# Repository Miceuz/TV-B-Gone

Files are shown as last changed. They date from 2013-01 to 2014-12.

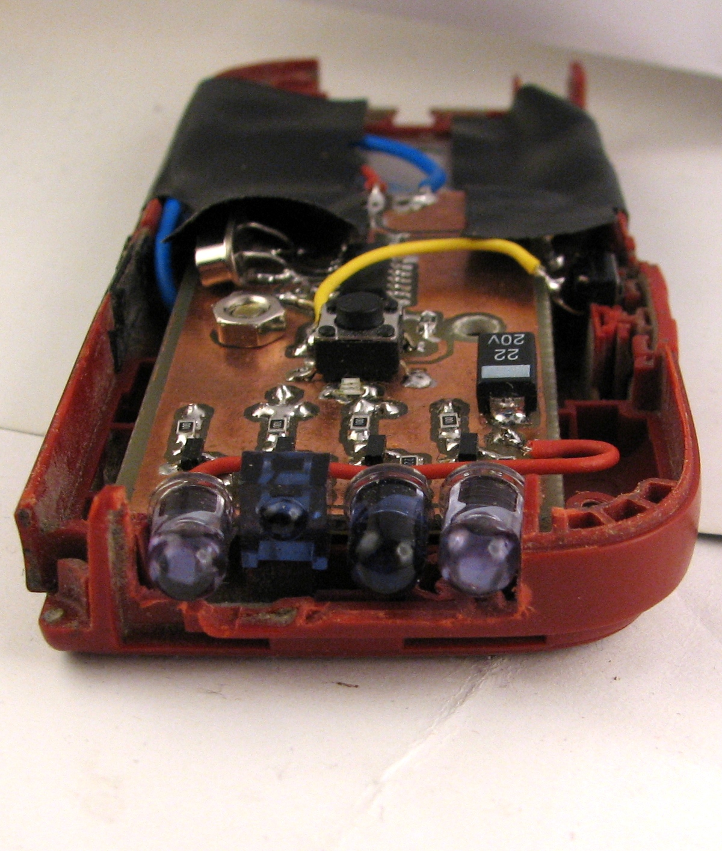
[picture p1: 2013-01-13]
pics/IMG_8425.JPG

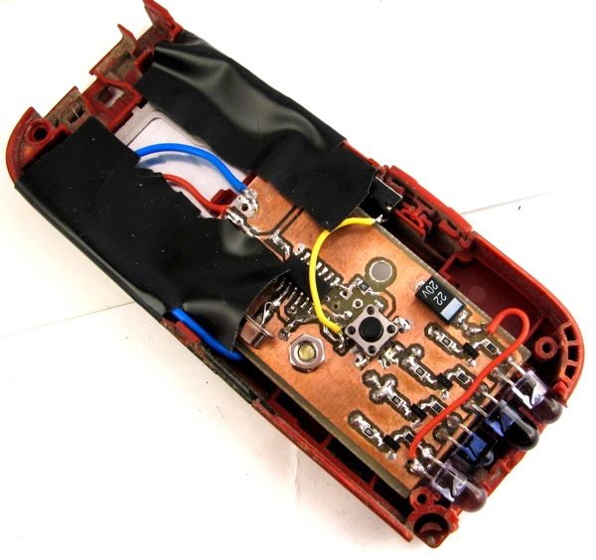
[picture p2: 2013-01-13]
pics/for web/IMG_8424.jpg

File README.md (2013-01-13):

TV-B-Gone
=========

This is my custom TV-be-gone implementation. The board was ment to fit on a standard double AA battery compartment. In general, this design was driven by what parts do I have available in my junk box, thus I've chosen Attiny44  as main microcontroller as I have plenty of them. Leds are driven by mosfets because I had some scavenged from some motherboard.

The code is from Adafruit - https://github.com/adafruit/TV-B-Gone-kit. I've removed all the codes for North American TVs and commented out the biggest codes for European TVs as Attiny44 does not have enough flash to fit them all. I've inverted PWM because I'm driving LEDs via N-channel mosfets, unlike BJTs in Adafruit version.

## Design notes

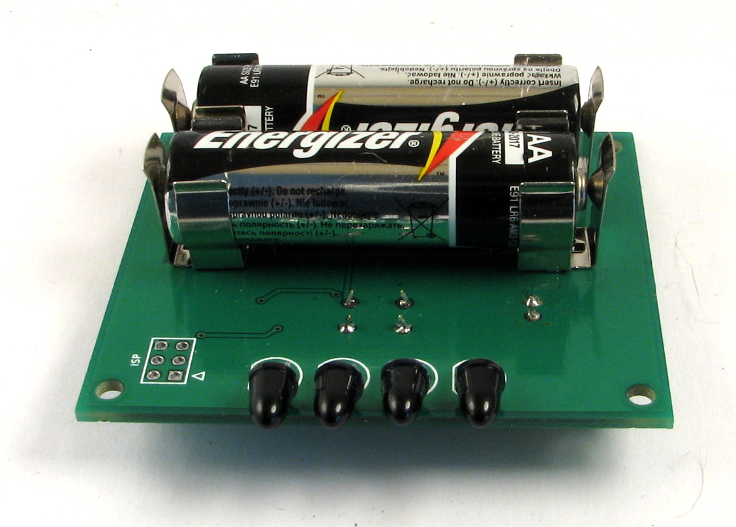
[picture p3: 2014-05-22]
tvbgone-workshop/pics/tv-b-gone-top.jpg

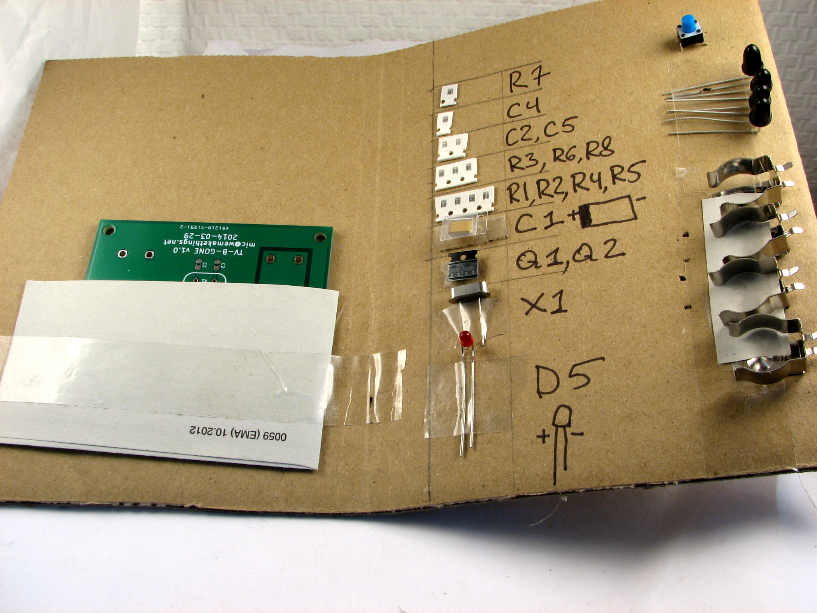
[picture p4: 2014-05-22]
tvbgone-workshop/pics/tv-b-gone-kit.jpg

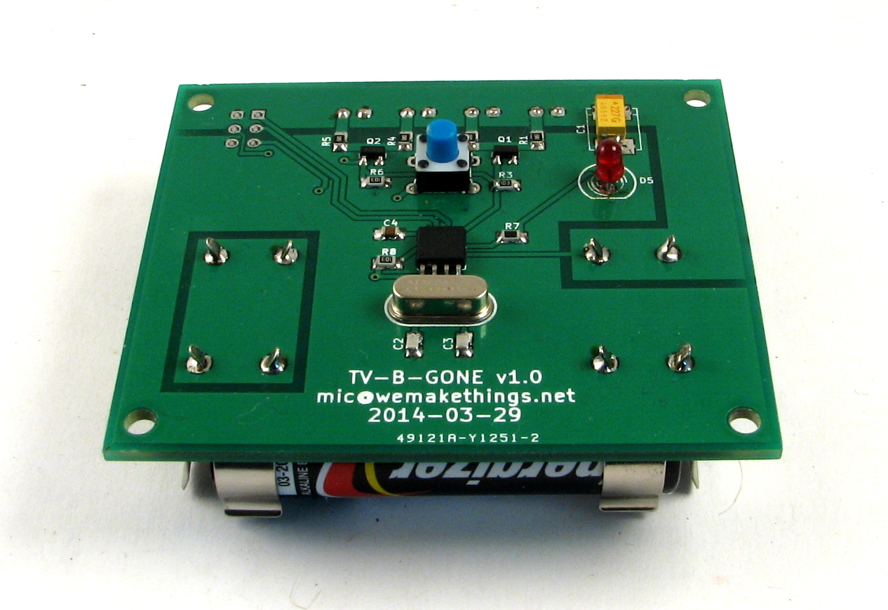
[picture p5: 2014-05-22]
tvbgone-workshop/pics/tv-b-gone-bottom.jpg

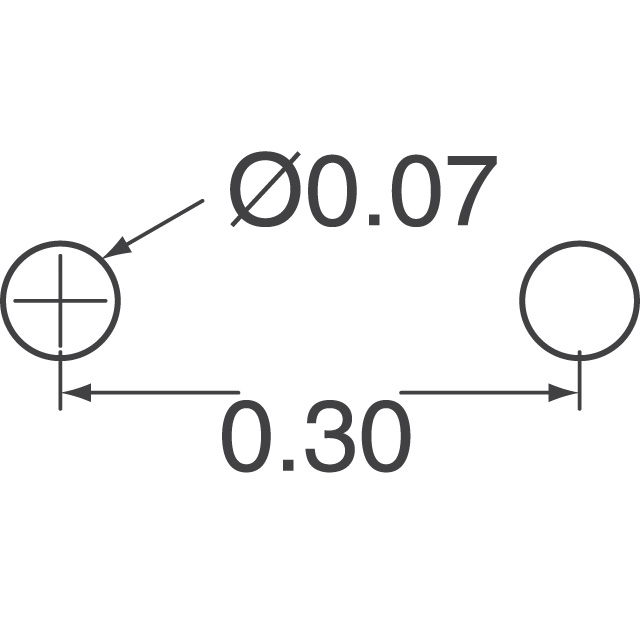
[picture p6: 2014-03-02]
tvbgone-workshop/BK-92FTPRNT.jpg

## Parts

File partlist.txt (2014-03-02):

Partlist

Exported from tvbgone-attiny85-pendant.brd at 2013/04/14/ 10:02 AM

EAGLE Version 5.11.0 Copyright (c) 1988-2010 CadSoft

Part     Value              Package        Library      Position (mil)        Orientation

B1                          EVQ-Q2         microbuilder (862.5 809.449)       R90
C1                          0603-CAP       SparkFun     (1175 1050)           R90
C3                          EIA7343-31/D-W microbuilder (250 300)             R0
C4                          0603-CAP       SparkFun     (937.5 462.5)         R180
C5                          0603-CAP       SparkFun     (1562.5 462.5)        R0
JP1                         1X02_LONGPADS  SparkFun     (562.5 950)           R180
JP2      AVR-ISP-6          AVR-ISP-6      avr-5        (1475 800)            MR270
LED1                        LED5MM         SparkFun     (1775 150)            R180
LED2                        LED5MM         SparkFun     (1325 150)            R0
LED3                        LED5MM         SparkFun     (875 150)             R0
LED4                        LED5MM         SparkFun     (425 150)             R0
LED5                        CHIP-LED0805   adafruit     (612.5 737.5)         R270
LED6                        CHIPLED_0805   adafruit     (1087.5 809.449)      R180
Q2       MOSFET-NCHANNELSMD SOT23-3        SparkFun     (1287.5 287.5)        R270
Q3       MOSFET-NCHANNELSMD SOT23-3        SparkFun     (837.5 287.5)         R270
Q5                          QS             special      (1250 550)            R180
R1                          0603-RES       SparkFun     (612.5 812.5)         R180
R2                          0603-RES       SparkFun     (1612.5 137.5)        R180
R3                          0603-RES       SparkFun     (1400 250)            R90
R4                          0603-RES       SparkFun     (950 250)             R90
R5                          0603-RES       SparkFun     (600 137.5)           R0
R6                          0603-RES       SparkFun     (1212.5 387.5)        R180
R7                          0603-RES       SparkFun     (762.5 387.5)         R180
R10                         0603-RES       SparkFun     (1087.5 950)          R270
R12                         0603-RES       SparkFun     (1187.5 287.5)        R270
R13                         0603-RES       SparkFun     (737.5 287.5)         R270
R16      1k                 0603-RES       SparkFun     (500 612.5)           R0
U$3      ATTINY45           SO08-EIAJ      SparkFun     (1250 800)            R0
U$4      USB-MINIB-5PIN     USB-MINIB      SparkFun     (212.5 650)           R0
U1       MCP73831           SOT23-5        SparkFun     (475 737.5)           R180
XTAL1                       HC-49U         dp_devices   (1250 550)            R180

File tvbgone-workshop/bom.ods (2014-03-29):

Name | Price (Euro) @ 10 pcs | Quantity | Price for 1 unit | Designator | Package | DigiKey link
ATTiny85 | 0.97 | 1 | 0.97 | IC1 | SO-8 | http://www.digikey.de/product-detail/en/ATTINY85-20SH/ATTINY85-20SH-ND/2238295
IR LED SFH 4545 | 0.53 | 4 | 2.12 | D1, D2, D3, D4 | Radial 5mm | http://www.digikey.de/product-detail/en/SFH%204545/475-2919-ND/2205955
MOSFET BSH103 | 0.304 | 2 | 0.608 | Q1, Q2 | SOT23 | http://www.digikey.de/product-detail/en/BSH103,215/568-5013-1-ND/2209929 http://www.digikey.de/product-detail/en/BSH105,215/568-6215-1-ND/2531502
Cap 220uF tantallum | 0.587 | 1 | 0.587 | C1 | C | http://www.digikey.de/product-detail/en/TAJC227K004RNJ/478-2346-1-ND/678514
Tact switch FSM6JH | 0.089 | 1 | 0.089 | SW1 | 6x6mm | http://www.digikey.de/product-detail/en/FSM6JH/450-1652-ND/1632538
Crystal 8MHz | 0.24 | 1 | 0.24 | X1 | HC49/US | http://www.digikey.de/product-detail/en/ATS08A/CTX406-ND/280186
Battery holder clip BK-92 | 0.169 | 4 | 0.676 | BT1, BT2 | BK-92 | http://www.digikey.de/product-search/en?keywords=BK-92&stock=1&ColumnSort=1000011&quantity=10
Resistor 560R | 0.014 | 1 | 0.014 | R7 | R0805 | http://www.digikey.de/product-detail/en/RC0805JR-07560RL/311-560ARCT-ND/731294
Resistor 15R | 0.037 | 4 | 0.148 | R1, R2, R4, R5 | R0805 | http://www.digikey.de/product-detail/en/RNCP0805FTD15R0/RNCP0805FTD15R0CT-ND/2240537
Cap 100nF ceramic | 0.025 | 2 | 0.05 | C4 | C0805 | http://www.digikey.de/product-detail/en/CC0805ZRY5V9BB104/311-1361-1-ND/2103145
Cap 22pF ceramic | 0.038 | 2 | 0.076 | C2, C3 | C0805 | http://www.digikey.de/product-detail/en/C0805C220J5GACTU/399-1113-1-ND/411388
LED red 3mm | 0.05927 | 1 | 0.05927 | D5 | Radial 3mm | http://www.digikey.de/product-detail/en/HLMP1700C6A0/1080-1048-2-ND/4271537
Resistor 10k | 0.014 | 3 | 0.042 | R3, R6, R9 | R0805 | http://www.digikey.de/product-detail/en/RC0805JR-0710KL/311-10KARCT-ND/731188
 |  | Total for parts | 5.67927
 |  | +21%VAT | 6.8719167
PCB @ seeedstudio | 4 | 1 | 4 |  | 53x64mm
ABS plastiko dėžutė (71x71x27)mm juoda, Q*PP42SW | 2 | 1 | 2 |  | 71x71x27mm | http://evita.lt/getPdf.php?id=17218
Šarminė baterija LR6(AA) 1.5V DURACELL | 0.72 | 2 | 1.44 |  | AA | http://evita.lt/det-15729-sarmine-baterija-lr6aa-1.5v-duracell.html
 |  | TOTAL (Euro): | 14.3119167

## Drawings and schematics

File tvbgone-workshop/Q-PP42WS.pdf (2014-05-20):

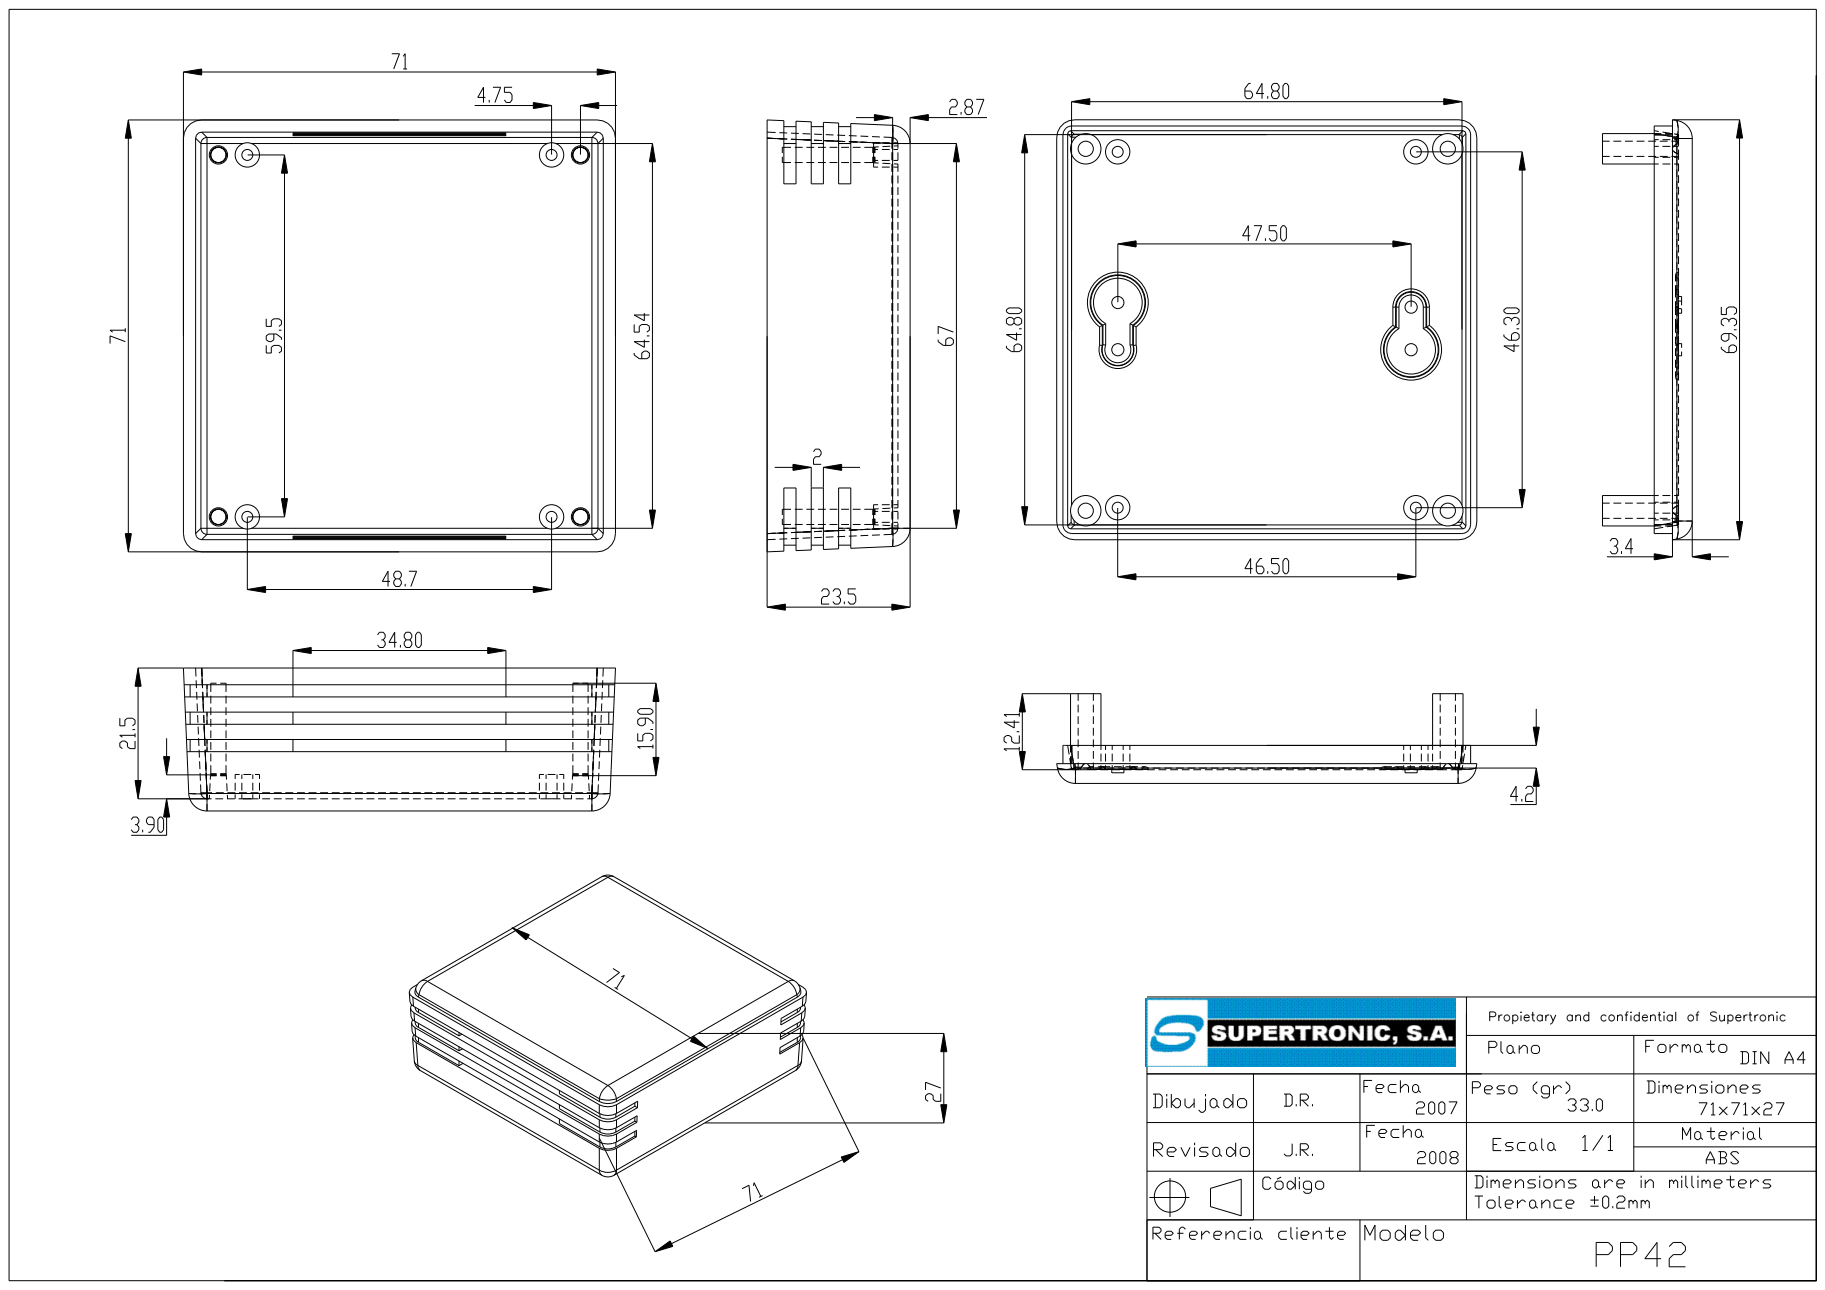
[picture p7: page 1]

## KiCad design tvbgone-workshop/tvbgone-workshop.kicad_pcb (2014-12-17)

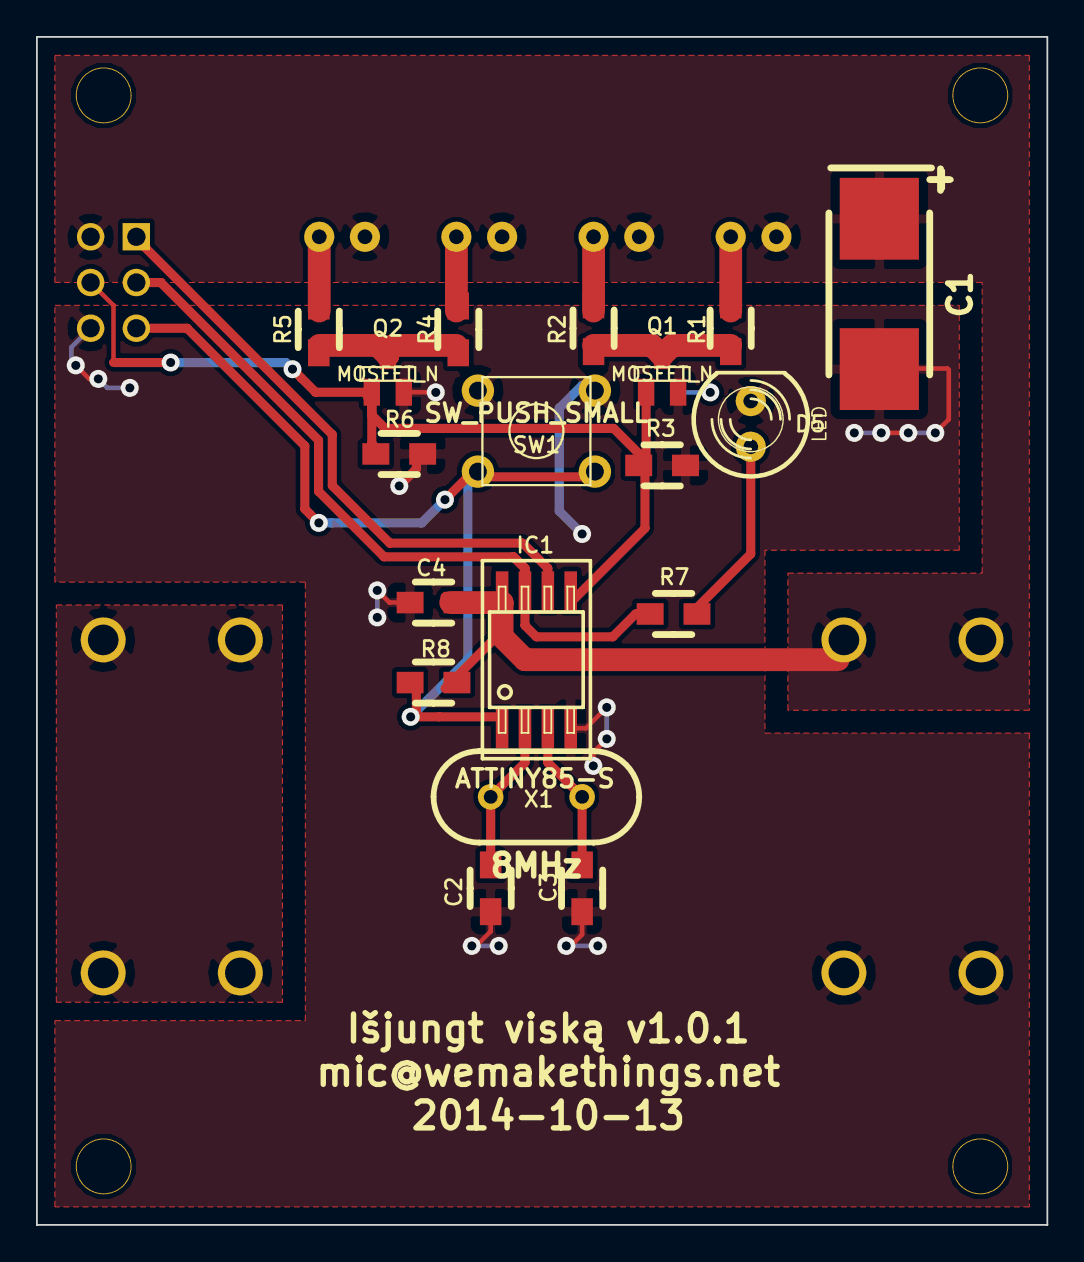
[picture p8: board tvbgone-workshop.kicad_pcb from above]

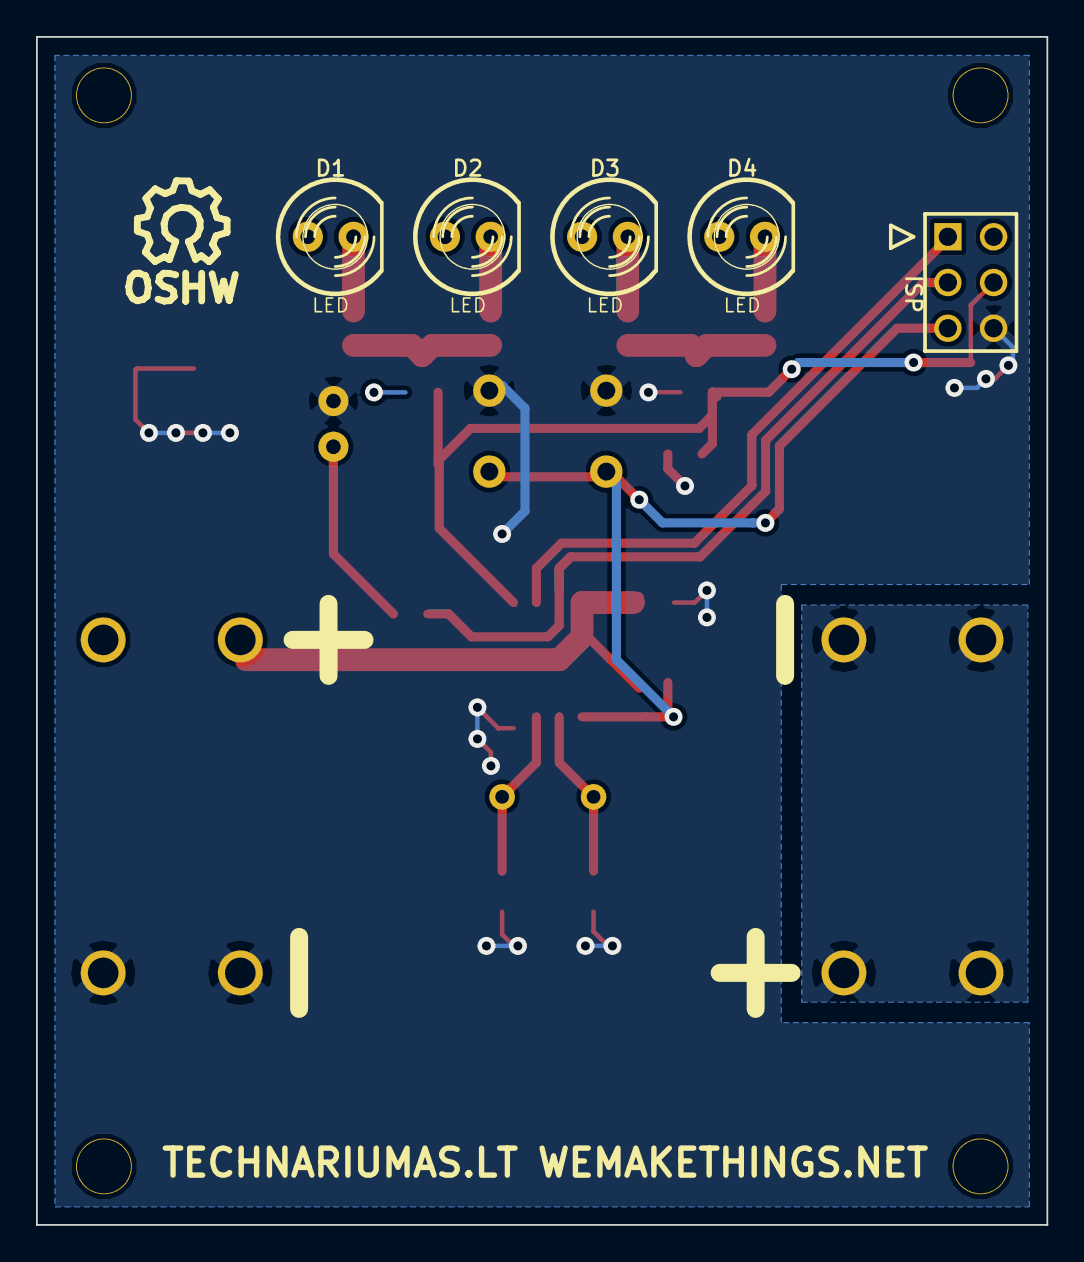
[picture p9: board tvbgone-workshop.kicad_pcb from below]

Board: 2 copper layers, 56.1 x 66.0 mm, 26 parts (8 on the bottom side), 16 nets.

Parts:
BT1: BATTERY; BATT-AA-BK92
BT2: BATTERY; BATT-AA-BK92-bold
C1: CAPAPOL; TantalC_SizeE_EIA-7360_HandSoldering
C2, C3: 22p; Resistor_SMD0805_HandSoldering
C4: 100n; Resistor_SMD0805_HandSoldering
D1, D2, D3, D4, D5: LED; LED-5MM
IC1: ATTINY85-S; SO8_200mil_wide
ISP: AVR-ISP-6; pin_array_3x2
Q1, Q2: MOSFET_N; SOT23GDS
R1, R2, R3, R4, R5, R6, R8: 10k; Resistor_SMD0805_HandSoldering
R7: 330; Resistor_SMD0805_HandSoldering
SW1: SW_PUSH_SMALL
SYM: Symbol_OSHW-Logo_SilkScreen_07Jul2012; Symbol_OSHW-Logo_SilkScreen
X1: 8MHz; HC-49V

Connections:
/MISO: IC1.6, ISP.1
/MOSI: IC1.5, ISP.4, Q1.G, Q2.G, R3.1, R6.1
/RESET: IC1.1, ISP.5, R8.1, SW1.1
/SCK: IC1.7, ISP.3, R7.2
GND: BT2.2, C1.2, C2.2, C3.2, C4.2, D5.2, IC1.4, ISP.6, Q1.S, Q2.S, R3.2, R6.2, SW1.2
unnamed: Q1.D, R1.2, R2.2
unnamed: Q2.D, R4.2, R5.2
unnamed: C3.1, IC1.3, X1.2
unnamed: C2.1, IC1.2, X1.1
unnamed: D5.1, R7.1
unnamed: BT1.2, BT2.1
unnamed: D3.2, R4.1
unnamed: D1.2, R1.1
unnamed: D2.2, R2.1
unnamed: D4.2, R5.1
VCC: BT1.1, C1.1, C4.1, D1.1, D2.1, D3.1, D4.1, IC1.8, ISP.2, R8.2

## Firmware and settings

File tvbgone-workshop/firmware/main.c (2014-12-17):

/*
TV-B-Gone Firmware version 1.2
for use with ATtiny85v and v1.2 hardware
(c) Mitch Altman + Limor Fried 2009
Last edits, August 16 2009

With some code from:
Kevin Timmerman & Damien Good 7-Dec-07

Distributed under Creative Commons 2.5 -- Attib & Share Alike

This is the 'universal' code designed for v1.2 - it will select EU or NA
depending on a pulldown resistor on pin B1 !
*/

#include <avr/io.h>             // this contains all the IO port definitions
#include <avr/eeprom.h>
#include <avr/sleep.h>          // definitions for power-down modes
#include <avr/pgmspace.h>       // definitions or keeping constants in program memory
#include <avr/wdt.h>
#include "main.h"


/*
This project transmits a bunch of TV POWER codes, one right after the other, 
with a pause in between each.  (To have a visible indication that it is 
transmitting, it also pulses a visible LED once each time a POWER code is 
transmitted.)  That is all TV-B-Gone does.  The tricky part of TV-B-Gone 
was collecting all of the POWER codes, and getting rid of the duplicates and 
near-duplicates (because if there is a duplicate, then one POWER code will 
turn a TV off, and the duplicate will turn it on again (which we certainly 
do not want).  I have compiled the most popular codes with the 
duplicates eliminated, both for North America (which is the same as Asia, as 
far as POWER codes are concerned -- even though much of Asia USES PAL video) 
and for Europe (which works for Australia, New Zealand, the Middle East, and 
other parts of the world that use PAL video).

Before creating a TV-B-Gone Kit, I originally started this project by hacking 
the MiniPOV kit.  This presents a limitation, based on the size of
the Atmel ATtiny2313 internal flash memory, which is 2KB.  With 2KB we can only 
fit about 7 POWER codes into the firmware's database of POWER codes.  However,
the more codes the better! Which is why we chose the ATtiny85 for the 
TV-B-Gone Kit.

This version of the firmware has the most popular 100+ POWER codes for 
North America and 100+ POWER codes for Europe. You can select which region 
to use by soldering a 10K pulldown resistor.
*/


/*
This project is a good example of how to use the AVR chip timers.
*/


/*
The hardware for this project is very simple:
     ATtiny85 has 8 pins:
       pin 1   RST + Button
       pin 2   one pin of ceramic resonator MUST be 8.0 mhz
       pin 3   other pin of ceramic resonator
       pin 4   ground
       pin 5   OC1A - IR emitters, through a '2907 PNP driver that connects 
               to 4 (or more!) PN2222A drivers, with 1000 ohm base resistor 
               and also connects to programming circuitry
       pin 6   Region selector. Float for US, 10K pulldown for EU,
               also connects to programming circuitry
       pin 7   PB0 - visible LED, and also connects to programming circuitry
       pin 8   +3-5v DC (such as 2-4 AA batteries!)
    See the schematic for more details.

    This firmware requires using an 8.0MHz ceramic resonator 
       (since the internal oscillator may not be accurate enough).

    IMPORTANT:  to use the ceramic resonator, you must perform the following:
                    make burn-fuse_cr
*/



extern const PGM_P * const NApowerCodes[] PROGMEM;
extern const PGM_P * const EUpowerCodes[] PROGMEM;
extern const uint8_t num_NAcodes, num_EUcodes;


/* This function is the 'workhorse' of transmitting IR codes.
   Given the on and off times, it turns on the PWM output on and off
   to generate one 'pair' from a long code. Each code has ~50 pairs! */
void xmitCodeElement(uint16_t ontime, uint16_t offtime, uint8_t PWM_code )
{
  // start Timer0 outputting the carrier frequency to IR emitters on and OC0A 
  // (PB0, pin 5)
  TCNT0 = 0; // reset the timers so they are aligned
  TIFR = 0;  // clean out the timer flags

  if(PWM_code) {
    // 99% of codes are PWM codes, they are pulses of a carrier frequecy
    // Usually the carrier is around 38KHz, and we generate that with PWM
    // timer 0
    TCCR0A =_BV(COM0A0) | _BV(WGM01);          // set up timer 0
    TCCR0B = _BV(CS00);
  } else {
    // However some codes dont use PWM in which case we just turn the IR
    // LED on for the period of time.
    PORTB |= _BV(IRLED);
  }

  // Now we wait, allowing the PWM hardware to pulse out the carrier 
  // frequency for the specified 'on' time
  delay_ten_us(ontime);
  
  // Now we have to turn it off so disable the PWM output
  TCCR0A = 0;
  TCCR0B = 0;
  // And make sure that the IR LED is off too (since the PWM may have 
  // been stopped while the LED is on!)
  PORTB &= ~_BV(IRLED);           // turn off IR LED

  // Now we wait for the specified 'off' time
  delay_ten_us(offtime);
}

/* This is kind of a strange but very useful helper function
   Because we are using compression, we index to the timer table
   not with a full 8-bit byte (which is wasteful) but 2 or 3 bits.
   Once code_ptr is set up to point to the right part of memory,
   this function will let us read 'count' bits at a time which
   it does by reading a byte into 'bits_r' and then buffering it. */

uint8_t bitsleft_r = 0;
uint8_t bits_r=0;
PGM_P code_ptr;

// we cant read more than 8 bits at a time so dont try!
uint8_t read_bits(uint8_t count)
{
  uint8_t i;
  uint8_t tmp=0;
  
  // we need to read back count bytes
  for (i=0; i<count; i++) {
    // check if the 8-bit buffer we have has run out
    if (bitsleft_r == 0) {
      // in which case we read a new byte in
      bits_r = pgm_read_byte(code_ptr++);
      // and reset the buffer size (8 bites in a byte)
      bitsleft_r = 8;
    }
    // remove one bit
    bitsleft_r--;
    // and shift it off of the end of 'bits_r'
    tmp |= (((bits_r >> (bitsleft_r)) & 1) << (count-1-i));
  }
  // return the selected bits in the LSB part of tmp
  return tmp; 
}


/*
The C compiler creates code that will transfer all constants into RAM when 
the microcontroller resets.  Since this firmware has a table (powerCodes) 
that is too large to transfer into RAM, the C compiler needs to be told to 
keep it in program memory space.  This is accomplished by the macro PROGMEM 
(this is used in the definition for powerCodes).  Since the C compiler assumes 
that constants are in RAM, rather than in program memory, when accessing
powerCodes, we need to use the pgm_read_word() and pgm_read_byte macros, and 
we need to use powerCodes as an address.  This is done with PGM_P, defined 
below.  
For example, when we start a new powerCode, we first point to it with the 
following statement:
    PGM_P thecode_p = pgm_read_word(powerCodes+i);
The next read from the powerCode is a byte that indicates the carrier 
frequency, read as follows:
      const uint8_t freq = pgm_read_byte(code_ptr++);
After that is a byte that tells us how many 'onTime/offTime' pairs we have:
      const uint8_t numpairs = pgm_read_byte(code_ptr++);
The next byte tells us the compression method. Since we are going to use a
timing table to keep track of how to pulse the LED, and the tables are 
pretty short (usually only 4-8 entries), we can index into the table with only
2 to 4 bits. Once we know the bit-packing-size we can decode the pairs
      const uint8_t bitcompression = pgm_read_byte(code_ptr++);
Subsequent reads from the powerCode are n bits (same as the packing size) 
that index into another table in ROM that actually stores the on/off times
      const PGM_P time_ptr = (PGM_P)pgm_read_word(code_ptr);
*/


int main(void) {
  uint16_t ontime, offtime;
  uint8_t i,j, Loop;
  uint8_t region = US;     // by default our code is US
  
  Loop = 0;                // by default we are not going to loop

  TCCR1 = 0;		   // Turn off PWM/freq gen, should be off already
  TCCR0A = 0;
  TCCR0B = 0;

  i = MCUSR;                     // Save reset reason
  MCUSR = 0;                     // clear watchdog flag
  WDTCR = _BV(WDCE) | _BV(WDE);  // enable WDT disable

  WDTCR = 0;                     // disable WDT while we setup

  DDRB = _BV(LED) | _BV(IRLED);   // set the visible and IR LED pins to outputs
//  PORTB = _BV(LED) |              //  visible LED is off when pin is high
//          _BV(IRLED) |            // IR LED is off when pin is high
//          _BV(REGIONSWITCH);     // Turn on pullup on region switch pin

  // check the reset flags
  if (i & _BV(BORF)) {    // Brownout
    // Flash out an error and go to sleep
    flashslowLEDx(2);	
    tvbgone_sleep();  
  }

  delay_ten_us(5000);            // Let everything settle for a bit

  // determine region
  if (PINB & _BV(REGIONSWITCH)) {
    region = US; // US
  } else {
    region = EU;
  }

  // Tell the user what region we're in  - 3 is US 4 is EU
  quickflashLEDx(3+region);
  
  // Starting execution loop
  delay_ten_us(25000);
  // turn on watchdog timer immediately, this protects against
  // a 'stuck' system by resetting it
  wdt_enable(WDTO_8S); // 1 second long timeout

  do {	//Execute the code at least once.  If Loop is on, execute forever.

    // We may have different number of codes in either database
    if (region == US) {
      j = num_NAcodes;
    } else {
      j = num_EUcodes;
    }

    // for every POWER code in our collection
    for(i=0 ; i < j; i++) {   
      //To keep Watchdog from resetting in middle of code.
      wdt_reset();

      // point to next POWER code, from the right database
      if (region == US) {
	code_ptr = (PGM_P)pgm_read_word(NApowerCodes+i);  
      } else {
	code_ptr = (PGM_P)pgm_read_word(EUpowerCodes+i);  
      }

      // Read the carrier frequency from the first byte of code structure
      const uint8_t freq = pgm_read_byte(code_ptr++);
      // set OCR for Timer1 to output this POWER code's carrier frequency
      OCR0A = freq; 
      // Get the number of pairs, the second byte from the code struct
      const uint8_t numpairs = pgm_read_byte(code_ptr++);

      // Get the number of bits we use to index into the timer table
      // This is the third byte of the structure
      const uint8_t bitcompression = pgm_read_byte(code_ptr++);

      // Get pointer (address in memory) to pulse-times table
      // The address is 16-bits (2 byte, 1 word)
      const PGM_P time_ptr = (PGM_P)pgm_read_word(code_ptr);
      code_ptr+=2;

      // Transmit all codeElements for this POWER code 
      // (a codeElement is an onTime and an offTime)
      // transmitting onTime means pulsing the IR emitters at the carrier 
      // frequency for the length of time specified in onTime
      // transmitting offTime means no output from the IR emitters for the 
      // length of time specified in offTime

      // For EACH pair in this code....
      for (uint8_t k=0; k<numpairs; k++) {
	uint8_t ti;
	
	// Read the next 'n' bits as indicated by the compression variable
	// The multiply by 4 because there are 2 timing numbers per pair
	// and each timing number is one word long, so 4 bytes total!
	ti = (read_bits(bitcompression)) * 4;

	// read the onTime and offTime from the program memory
	ontime = pgm_read_word(time_ptr+ti);  // read word 1 - ontime
	offtime = pgm_read_word(time_ptr+ti+2);  // read word 2 - offtime

	// transmit this codeElement (ontime and offtime)
	xmitCodeElement(ontime, offtime, (freq!=0));  
      } 
      
      //Flush remaining bits, so that next code starts
      //with a fresh set of 8 bits.
      bitsleft_r=0;	

      // delay 250 milliseconds before transmitting next POWER code
      delay_ten_us(25000);
      
      // visible indication that a code has been output.
      quickflashLED(); 
    }
  } while (Loop == 1);
  
  // We are done, no need for a watchdog timer anymore
  wdt_disable();

  // flash the visible LED on PB0  4 times to indicate that we're done
  delay_ten_us(65500); // wait maxtime 
  delay_ten_us(65500); // wait maxtime 
  quickflashLEDx(4);

  tvbgone_sleep();
}


/****************************** SLEEP FUNCTIONS ********/

void tvbgone_sleep( void )
{
  // Shut down everything and put the CPU to sleep
  TCCR0A = 0;           // turn off frequency generator (should be off already)
  TCCR0B = 0;           // turn off frequency generator (should be off already)
  PORTB &= ~_BV(LED);       // turn off visible LED
  PORTB &= ~_BV(IRLED);     // turn off IR LED

  wdt_disable();           // turn off the watchdog (since we want to sleep
  delay_ten_us(1000);      // wait 10 millisec

  MCUCR = _BV(SM1) |  _BV(SE);    // power down mode,  SE enables Sleep Modes
  sleep_cpu();                    // put CPU into Power Down Sleep Mode
}


/****************************** LED AND DELAY FUNCTIONS ********/


// This function delays the specified number of 10 microseconds
// it is 'hardcoded' and is calibrated by adjusting DELAY_CNT 
// in main.h Unless you are changing the crystal from 8mhz, dont
// mess with this.
void delay_ten_us(uint16_t us) {
  uint8_t timer;
  while (us != 0) {
    // for 8MHz we want to delay 80 cycles per 10 microseconds
    // this code is tweaked to give about that amount.
    for (timer=0; timer <= DELAY_CNT; timer++) {
      NOP;
      NOP;
    }
    NOP;
    us--;
  }
}


// This function quickly pulses the visible LED (connected to PB0, pin 5)
// This will indicate to the user that a code is being transmitted
void quickflashLED( void ) {
  PORTB |= _BV(LED);   // turn on visible LED at PB0 by pulling pin to ground
  delay_ten_us(3000);   // 30 millisec delay
  PORTB &= ~_BV(LED);    // turn off visible LED at PB0 by pulling pin to +3V
}

// This function just flashes the visible LED a couple times, used to
// tell the user what region is selected
void quickflashLEDx( uint8_t x ) {
  quickflashLED();
  while(--x) {
  	wdt_reset();
	delay_ten_us(15000);     // 150 millisec delay between flahes
	quickflashLED();
  }
  wdt_reset();                // kick the dog
}

// This is like the above but way slower, used for when the tvbgone
// crashes and wants to warn the user
void flashslowLEDx( uint8_t num_blinks )
{
  uint8_t i;
  for(i=0;i<num_blinks;i++)
    {
      // turn on visible LED at PB0 by pulling pin to ground
      PORTB |= _BV(LED);    
      delay_ten_us(50000);         // 500 millisec delay
      wdt_reset();                 // kick the dog
      // turn off visible LED at PB0 by pulling pin to +3V
      PORTB &= ~_BV(LED);          
      delay_ten_us(50000);	   // 500 millisec delay
      wdt_reset();                 // kick the dog
    }
}

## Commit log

2013-01-21 + attiny85 version
    [tvbgone-attiny85.brd, tvbgone-attiny85.sch]
2013-01-21 some more fixes
    [tvbgone-attiny85.brd, tvbgone-attiny85.sch]
2014-03-02 working on a kit for a workshop, some alpha board and BOM
    [bom.ods, parport.brd, tvbgone-attiny85-pendant.brd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]
2014-03-29 latest changes
    [bom.ods, tvbgone-workshop.sch]
2014-03-30 add holes, changes size of the board a bit, shuffle stuf around
    [tvbgone-workshop.kicad_pcb]
2014-03-30 add gerbers
    [tvbgone-workshop-B_Cu.gbl, tvbgone-workshop-B_Mask.gbs, tvbgone-workshop-B_SilkS.gbo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]
2014-05-20 changed orientation of the board, distances to holes according to case drawings
2014-05-22 changed MCU package, a bit more silkscreen markings for batteries and a polar cap
    [tvbgone-workshop.kicad_pcb]
2014-05-22 move to the new kicad, play around with 3d packages, make pads bigger for easier soldering
    [tvbgone-workshop.kicad_pcb]
2014-12-17 some leftovers
    [tvbgone-workshop.kicad_pcb]
2014-12-17 add the latest gerbers
    [tvbgone-workshop-B_Cu.gbr, tvbgone-workshop-B_Mask.gbr, tvbgone-workshop-B_SilkS.gbr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]
